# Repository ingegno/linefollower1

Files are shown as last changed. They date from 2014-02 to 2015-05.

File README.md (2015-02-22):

linefollower1
=============

_Arduino code voor een lijn volg robot met object detectie, zoals geleerd bij Ingegno Team 2013-2014 workshop, zie [ingegno.be](http://ingegno.be)._

Arduino code for a line following robot, with object detection, as teached at Ingegno Team 2013-2014 workshop, see [ingegno.be](http://ingegno.be).

## Lasercut frame

_Gebruik het frame in  [frame_redder.svg] (../master/frame/frame_redder.svg) als basis voor je robot. Geen toegang tot een lasercutter? Gebruik dan een plank van 7x12 cm, 3mm dik, als basis._

Use the frame from [frame_redder.svg] (../master/frame/frame_redder.svg)  as basis for your robot. No lasercutter? Use a piece of 7x12cm as basis, 3mm thick. 

## BOM

- Arduino Uno
- Afstandssensor 
- 2 x Lijnsensor
- 2 Servo motoren
- 2x 2AA Batterijpak
- Veel draadjes
-  Mini schakelbord (breadboard)
- Een schakelaar
- Zwenkwiel
- Bouten en moeren
- 4x AA batterijen
- Wielen (bv Nutella doppen)
- een frame (plank 7x12 cm of ons lasercut frame

## Lessons

_Doe de sketches in [de sketches folder] (../master/sketches) een voor een onder begeleiding._

Do the sketches in [the sketches folder] (../master/sketches) one by one under supervision.

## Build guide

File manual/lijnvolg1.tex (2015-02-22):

\section{\engt{Appendix} \nedt{Appendix}}
\eng{TODO
}

\ned{Lijnvolg sketches
}

\subsection{\engt{Test Servo} \nedt{Test Servo's}}
\eng{todo}
\ned{Volgende code bevat hoe je de Servo motoren kunt controleren. De eerste sketch toont hoe je precies een Servo definieert in Arduino code, en hoe je opdrachten ernaar stuurt.}

\begin{code}[les01\_servo.ino]\label{c:a1_servo}
 \ \newline
\inputardfull{\string"../sketches/les01_servo/les01_servo.ino\string"}
\end{code}

\eng{todo}
\ned{Doe wat testen met bovenstaande code. Het is voor het verdere verloop belangrijk dat je functionaliteit van je robot opsplitst in deeltjes die apart niet moeilijk zijn om te verstaan. Zo hou je overzicht over het geheel. Onze volgende code herschrijft het aansturen van de servo motoren in zo'n codeblokjes, welke we functies noemen: je krijgt input, je doet daar iets mee, en dan eindig je.}

\begin{code}[les02\_servo\_functies]\label{c:a2_servof}
 \ \newline
\inputardfull{\string"../sketches/les02_servo_functies/les02_servo_functies.ino\string"}
\end{code}

\subsection{\engt{Test Distance Sensor} \nedt{Test Afstandssensor}}
\eng{todo}
\ned{Volgende code bevat een eenvoudige en een iets vluggere, maar moeilijkere, methode om de afstand tot een object te bepalen. Met een basiskennis Arduino kun je de code lezen. De workshop begeleider om raad vragen bij problemen!}

\begin{code}[les03\_afstandsensor.ino]\label{c:a3_distsens}
 \ \newline
\inputardfull{\string"../sketches/les03_afstandsensor/les03_afstandsensor.ino\string"}
\end{code}

\eng{todo}
\ned{De afstandssensor heb je getest, en je begrijpt hoe hij werkt. We hebben een bibliotheek geschreven om gemakkelijk met afstandssensoren te werken: DistSens.h. Maak een nieuwe sketch die die de bibliotheek gebruikt om de afstand te bekomen. Je dient het bestand DistSens.h in dezelfde folder op te slaan als je sketch (.ino bestand). 

De bibliotheek heeft volgende handleiding: 

Een afstandssensor wordt geactiveerd door een instantie van de \ardo{DistSens} klasse te maken, en de trigger en echo pin door te geven via de \ardo{attach()} methode. Je kan daarna de afstand op verschillende manieren opvragen. 
}
\nedt{
De methodes van een DistSens object zijn: 
\begin{itemize}
 \item \ardo{attach(pintrig, pinecho)} -  Welke pinnen gebruiken
 \item \ardo{stop()} - deactiveer, alle afstanden zullen 0 teruggeven
 \item \ardo{start()} - activeer terug na deactivering
 \item \ardo{setMinMax(min, max)} - Geef minimum en maximum afstand om te meten. Default: 3.5cm en 50cm
 \item \ardo{setResolution(res)} - Zet laagste interval waarna opnieuw meten afstand toegelaten is. Default = 250000UL = 250 millisec = 1/4 sec. \newline
 Een meting voor dit interval afgelopen is zal de vorige gemeten afstand teruggeven.
 \item \ardo{distSimple()} - afstandsmeting die je sketch blokkeert tot meting gedaan is, wat een ongekende hoeveelheid tijd is.
 \item \ardo{distTimeout()} - afstandsmeting die je sketch blokkeert voor maximaal te tijd nodig om de max afstand doorgegeven met \ardo{setMinMax} te metn + 1ms. Deze tijd is 
 2*max/(speed of sound) + 1
 \item \ardo{distNoblock()} - afstandsmeting die altijd een waarde teruggeeft in minder dan 1 milliseconde. De laatst gedane meting wordt teruggegeven zolang geen nieuwe meting be\"eindigt is. Deze method geeft enkele correcte resultaten als het opgeroepen wordt vanuit een \ardo{loop()} functie van je Arduino die niet van \ardo{delay()} gebruik maakt. Gebruik deze methode als je verschillende sensoren hebt om op te reageren en je niet wil dat de afstandssensor de reactie blokkeert (PS: wil je nog beter, gebruik dan interrupts, dit zit niet in deze bibliotheek).
\end{itemize}

Een voorbeeld van gebruik van deze bibliotheek is je autorobot met servo's en een afstandsensor een hindernissen parcours laten afwerken: rij door een kamer zonder ergens tegen te botsen!
}

\begin{code}[les04\_ontwijkobjecten.ino]\label{c:a4_distsens}
 \ \newline
\inputardfull{\string"../sketches/les04_ontwijkobjecten/les04_ontwijkobjecten.ino\string"}
\end{code}

\subsection{\engt{Test Line Sensor} \nedt{Test Lijnsensor}}
\eng{todo}
\ned{Test nu de lijnsensoren. Je moet ze zo plaatsen dat ze het verschil zien tussen een zwarte lijn en de rest. Volgende code gebruikt de seri\"ele monitor om te laten weten wat we uitlezen.}

\begin{code}[les06\_lijnsensor.ino]\label{c:a6}
 \ \newline
\inputardfull{\string"../sketches/les06_lijnsensor/les06_lijnsensor.ino\string"}
\end{code}

\subsection{\engt{Line Follower} \nedt{Lijnvolg robot}}
\eng{todo}
\ned{We hebben alles voor een lijnvolg robot. Alle stukjes samenvoegen en dan een strategie om hoe je reageert op de meting van de lijnsensor. Een goede strategie is niet te vlug te rijden, en dan bij het zien van de lijn links of rechts te draaien rond de as. }

\begin{code}[les07\_lijnvolgen.ino]\label{c:a7}
 \ \newline
\inputardfull{\string"../sketches/les07_lijnvolgen/les07_lijnvolgen.ino\string"}
\end{code}
%\begin{code}\label{c:l2_motor}
% \ \newline
%\inputard{\string"../sketches/calib_motors_rotate_axis/calib_motors_rotate_axis.ino\string"}{37}{54}
%\end{code}

%  we need a multiple of 4 as number of page!
\newpage

\begin{center}
\textcopyright 2015 Ingegno.be                                         \end{center}

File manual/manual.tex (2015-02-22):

\documentclass[8pt,a5paper]{article}
%\usepackage{a4wide}

\usepackage[english,dutch]{babel}
% better color management than parallel:
\usepackage{pdfcolparallel}

\setlength{\columnsep}{0.5cm}

%\usepackage{parallel}
\usepackage{color}
\usepackage{amsmath}
\usepackage{graphicx}

\usepackage{inconsolata} %a different monofont, texlive-fonts-extra needed!

\usepackage{arduinohighlight}

\usepackage{xcolor}
\usepackage{framed}
\colorlet{shadecolor}{gray!50}

\usepackage[
      %dvipdfm,    %put here the correct(!) driver you are using
      pdftex,
      unicode,
      colorlinks=true,    %no frame around URL
      urlcolor=blue,    %blue color
      menucolor=black,    %no colors
      linkcolor=blue,    %blue color
      bookmarks=true,    %tree-like TOC
      bookmarksopen=true,    %expanded when starting
      hyperfootnotes=false,    %no referencing of footnotes, does not compile
      pdfpagemode=UseOutlines,    %show the bookmarks when starting the pdf viewer
      pdfauthor={Ingegno.be},
      pdftitle={Line Follower - Ingegno.be},
]{hyperref}

\newtheorem{opdrE}{Task} 
\newenvironment{doE}
  {\begin{shaded}\begin{opdrE}}
  {\end{opdrE}\end{shaded}}

\newtheorem{opdrN}{Opdracht} 
\newenvironment{doN}
  {\begin{shaded}\begin{opdrN}}
  {\end{opdrN}\end{shaded}}
\newtheorem{code}{Code} 

%% First to \eng, then \ned, closes automatically with a paragraph
% \newcommand{\eng}[1]{\selectlanguage{english} \ParallelLText{#1}}
% \newcommand{\ned}[1]{\selectlanguage{dutch} \ParallelRText{#1} \ParallelPar}
% \newcommand{\engt}[1]{{#1} - }
% \newcommand{\nedt}[1]{{#1}}
% \newcommand{\engo}[1]{\eng {#1}}
% \newcommand{\nedo}[1]{\ned {#1}}

%% Use following for book in English language
% \usepackage{multicol}
% %\newcommand{\eng}[1]{\selectlanguage{english} {#1}}
% \newcommand{\eng}[1]{\begin{multicols}{2}{\selectlanguage{english} {#1}}\end{multicols} \hrule}
% \newcommand{\ned}[1]{ }
% \newcommand{\engt}[1]{{#1}}
% \newcommand{\nedt}[1]{ }
% \newcommand{\nedo}[1]{ }
% \newcommand{\engo}[1]{\selectlanguage{english} {#1}}

%% Use following for book in Dutch language
\usepackage{multicol}
%\newcommand{\ned}[1]{\selectlanguage{dutch} {#1}}
\newcommand{\ned}[1]{\begin{multicols}{2}{\selectlanguage{dutch} {#1}}\end{multicols} \hrule}
\newcommand{\eng}[1]{ }
\newcommand{\nedt}[1]{{#1}}
\newcommand{\engt}[1]{ }
\newcommand{\engo}[1]{ }
\newcommand{\nedo}[1]{\selectlanguage{dutch} {#1}}

%\selectlanguage{english}
% \ParallelLText{\blindtext}
%\selectlanguage{dutch}
%\ParallelRText{\blindtext}
%\ParallelPar

	\addtolength{\oddsidemargin}{-.5in}
	\addtolength{\evensidemargin}{-.5in}
	\addtolength{\textwidth}{1.in}

	\addtolength{\topmargin}{-.5in}
	\addtolength{\textheight}{1.25in}

\begin{document}

 \title{Lijnvolger robot!}
 \author{Ingegno Team: M.C. Ciocci, B. Malengier}
 \date{\today}
 \maketitle

\begin{figure}[h]
  \centering
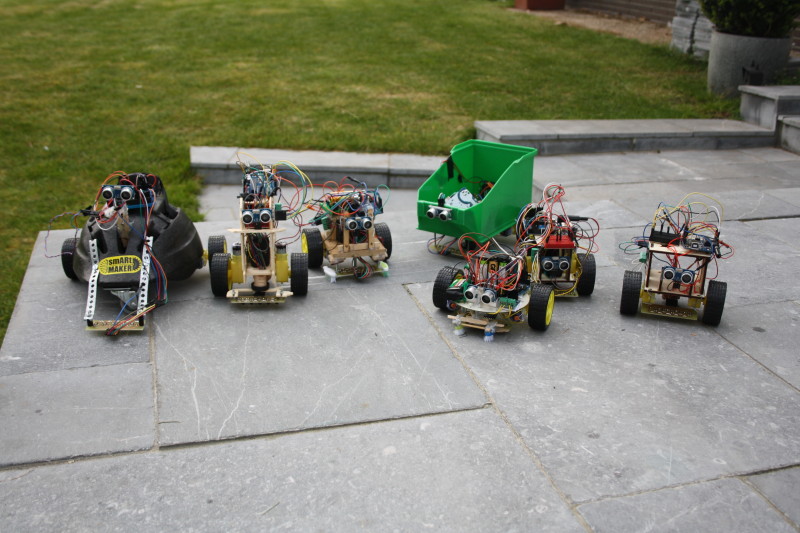
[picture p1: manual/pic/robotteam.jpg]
  
  
%\caption{\engt{Ingegno line following robots}
%\nedt{Ingegno lijnvolg robots}}
\label{f:ingrobots}       % Give a unique label
\end{figure}

\begin{Parallel}{7.5cm}{7.5cm}

\input{lijnvolg1}

\end{Parallel}
\end{document}

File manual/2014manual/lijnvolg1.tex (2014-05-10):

\section{\engt{Introduction} \nedt{Introductie}}
\eng{TODO
}

\ned{We maken een lijnvolg robot. Dit is een ingewikkeld project, met veel programmatie. Je kan het op twee manieren aanpakken: de bijgeleverde programma's als gegeven beschouwen en je concentreren op het optimaal maken van de robot. Je kan met de uitleg van deze handleiding de delen van de programma's die meest invloed hebben op het gedrag aanpassen. Kun je al wat meer, probeer dan ook de programma's door te nemen.
}

\subsection{\engt{The components} \nedt{De componenten}}
\eng{We will need the following components: 
\begin{enumerate}
 \item Arduino Uno
 \item Motor Shield 2.5V to max 12V
 \item Echo distance sensor 
 \item line scan sensor
 \item 2 motors (sufficiently powerfull!)
 \item Arduino connector for power to 9V
 \item many wires
 \item mini breadboard
 \item two switches to interrupt the power easily
\end{enumerate}
You will also need a soldering iron, and construction material for the robot. We offer some lasercut designs, but you can use whatever design you like as long as all components fit on it.

For an overview of meaning of the components, see the cheat sheet distributed seperately.
}

\ned{We zullen volgende componenten gebruiken: 
\begin{enumerate}
 \item Arduino Uno
 \item Motor Shield 2.5V tot max 12V
 \item Echo afstandssensor 
 \item line scan sensor
 \item 2 motoren (voldoende krachtig!)
 \item Arduino connector voor stroom naar 9V
 \item veel draden
 \item mini schakelbord
 \item twee schakelaars om de stroom snel te kunnen uitschakelen
\end{enumerate}
Je zal ook een soldeerijzer nodig hebben, en constructiemateriaal voor je robot. We geven een aantal lasercut ontwerpen, maar je kan gelijk welk design gebruiken die je wil, zolang alle componenten er maar op passen.

Voor een overzicht van de betekenis van de componenten, zie het overzicht die je apart gekregen hebt.
}

\subsection{Arduino}
\eng{We will make intensive use of Arduino, so you need to install the \href{http://Arduino.cc}{Arduino software}. Once installed, you can connect the Arduino to your PC via de \textsc{usb} port.  In the programming environment you installed you can write programs, and load those on the Arduino board. They will be executed there as long as the Arduino has power.

}
\ned{We zullen intensief gebruik maken van Arduino, dus moet je de \href{http://Arduino.cc}{Arduino software} installeren op je laptop.
Eenmaal geinstalleerd kun je nu je Arduino koppelen aan je computer via de \textsc{usb} poort. In de programmeeromgeving van Arduino kun je programma's schrijven en die opladen naar de Arduino, waar ze dan uitgevoerd worden zolang er stroom is.
}

\subsection{\engt{Programming with Arduino} \nedt{Programmeren met Arduino}}
\eng{A programming language needs to be understood by a computer. Unfortunately computers are still a little bit dumb, so you are not allowed to make errors! It's like a writing contest in which you need to obtain a 10/10 every time. So take time to learn the form of the language. See the specific sheet 'Programming with Arduino' distributed with this manual.}

\ned{Een programmeertaal moet verstaan worden door een computer. Spijtig genoeg zijn computers nog altijd een beetje dom, dus mag je geen enkele fout maken! Het is zoals een dictee waar je altijd 10/10 moet halen. Neem dus de tijd om de structuur en taal van de Arduino te leren. Zie de blaadjes 'Programmeren met Arduino' die je bij deze gids kan downloaden.}

\section{\engt{Lesson 1: Start! Construction time} \nedt{Les 1: Start! Constuctie}}

\subsection{\engt{Wiring} \nedt{Bedrading}}
\eng{TODO}
\ned{In Figuur \ref{f:wiring} zie je hoe al de componenten aan elkaar moeten verbonden worden. Al deze zaken moeten op je robot passen. De bedrading die je ziet kun je vooraf maken, en dan bepalen hoe je een frame zult maken, en hoe je alles op elkaar zult passen. Het uittesten van alle componenten doen we dan later (al dan niet als het al op een frame zit). 

Voor de AA batterijen die voor Vin zorgen kun je ook krachtige Li-ion batterijen gebruiken. Zorg wel dat je niet meer dan 12V gebruikt. De AA batterijen kunnen veel stroom leveren, wat nodig is voor de motoren. De 9V batterij gebruiken we om de Arduino aan te sturen. Deze 9V batterij kan niet veel stroom leveren, maar de sensoren en de Arduino chip hebben niet veel stroom nodig, dus dat is ok.

Het motor shield die je hebt ziet er niet uit zoals op de figuur. Het concept is hetzelfde evenwel, je hebt 4 schroefconnectors voor de batterijen, 2 voor links, 2 voor rechts. Dan heb je 2 linkse pinnen: PWM en DIR, 2 rechtse pinnen: PWM en DIR. Deze zijn voor de controle van de motoren: hoe snel moeten ze gaan. En dan nog Vin en GND pinnen voor de stroom.

De echo-locator herken je aan de twee ogen. Zet ze niet te hoog zodat je obstakels kunt zien. Er zijn 4 pinnen aan deze sensor: Trig en Echo om de afstand tot een object te bepalen, en dan de VCC en GND voor de stroom, welke 5V \textbf{moet} zijn. 

De lijn scanner heeft 7 pinnen. Voor de stroom opnieuw een VCC en GND, welke opnieuw 5V \textbf{moet} leveren, en dan nog 5 pinnen voor de 5 sensoren die je onderaan ziet. Opgelet, deze sensoren moeten ongeveer 3mm boven de grond hangen. Maak dus een constructie die je toelaat dit wat aan te passen zodat je de juiste hoogte kan instellen.

We gebruiken een mini-schakelbord om correct stroom te leveren. Gebruik een kant voor GND en 5V, en een andere kant voor GND en Vin van de AA batterijen. Schrijf het met alcohol stift op de zijkant, zodat je zeker niet mist. Teveel stroom op de sensoren of de Arduino \textbf{zal} deze kapot maken!
}

\begin{figure}
  \centering
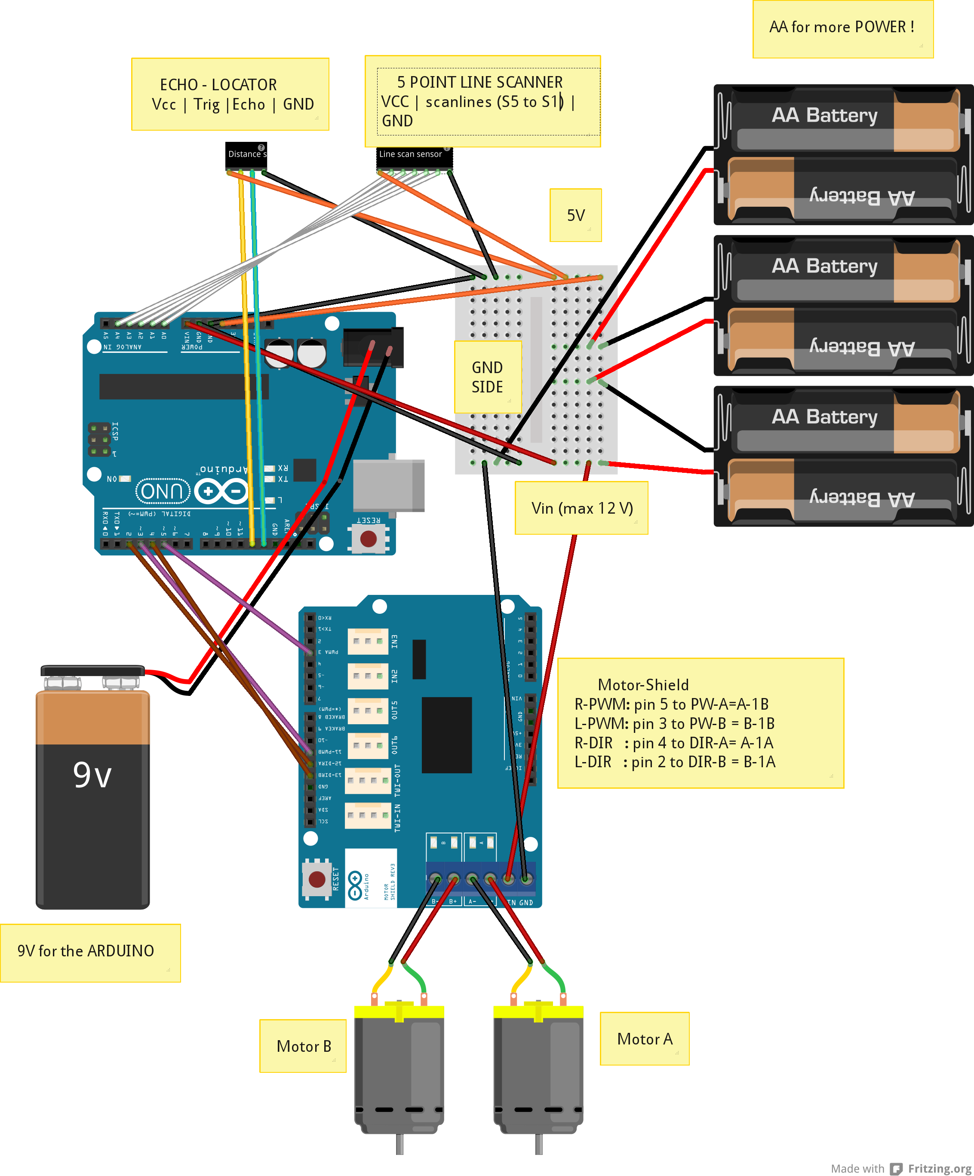
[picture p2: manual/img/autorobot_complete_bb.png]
  
\caption{\engt{The full wiring, all of this must fit on your robot}
\nedt{De volledige bedrading, dit moet helemaal op je robot passen}}
\label{f:wiring}       % Give a unique label
\end{figure}

\subsection{\engt{Construction} \nedt{Constructie}}

\begin{figure}[h]
  \centering
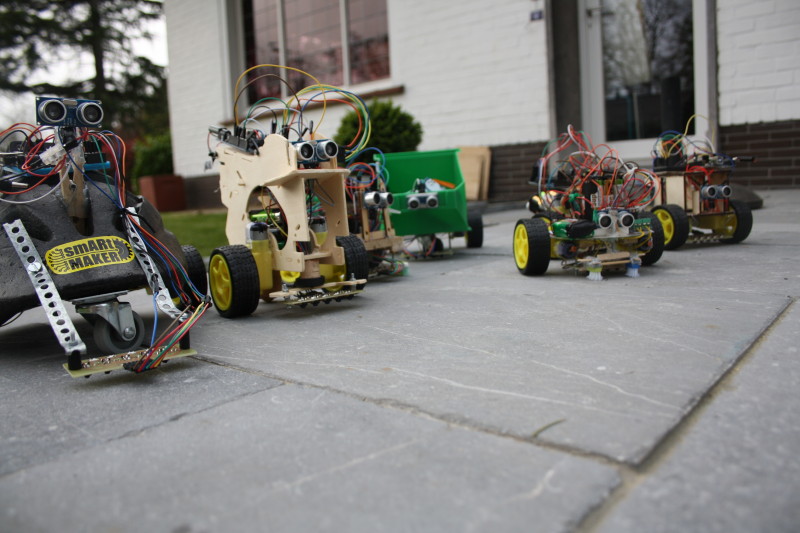
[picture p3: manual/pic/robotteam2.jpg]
  
\caption{\engt{Ingegno line following robots}
\nedt{Ingegno lijnvolg robots}}
\label{f:ingrobots2}
\end{figure}

\eng{TODO}
\ned{Je weet wat er op je robot moet komen, en kunt dus nu een eigen constructie maken uit materiaal die je hebt liggen. Voorbeelden zie je in Figuur \ref{f:ingrobots2}. 

Wil je optimaal werken, dan kun je een frame laten laseren in een fablab in de buurt. Je kan ontwerpfiles vinden in de map \url{https://github.com/ingegno/linefollower1/blob/master/frames/}. Wij zullen frame \textbf{basic} gebruiken. Alle stukken van basic zie je in Figuur \ref{f:frame_basic}, alsook de finale vorm. Voor de stevigheid gebruik je best ook lijm. Dit kan met houtlijm , of, veel gemakkelijker, met een lijmpistool.
}

\begin{figure}[h]
  \centering
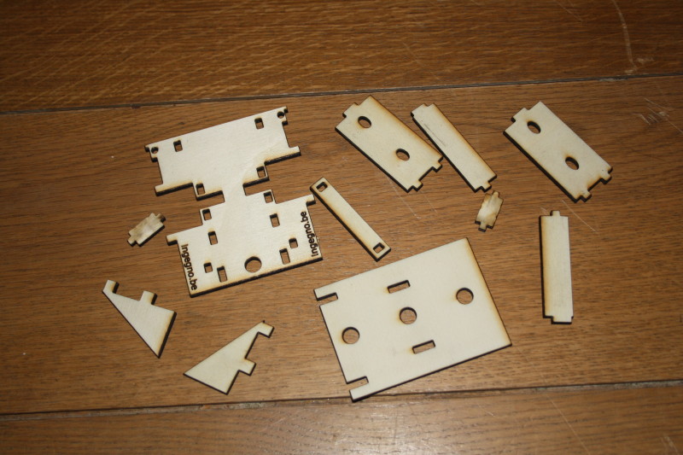
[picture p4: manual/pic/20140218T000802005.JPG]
  
%\rotatebox{-90}{\includegraphics[width=6cm]{pic/20140218T003500016.JPG}} \\
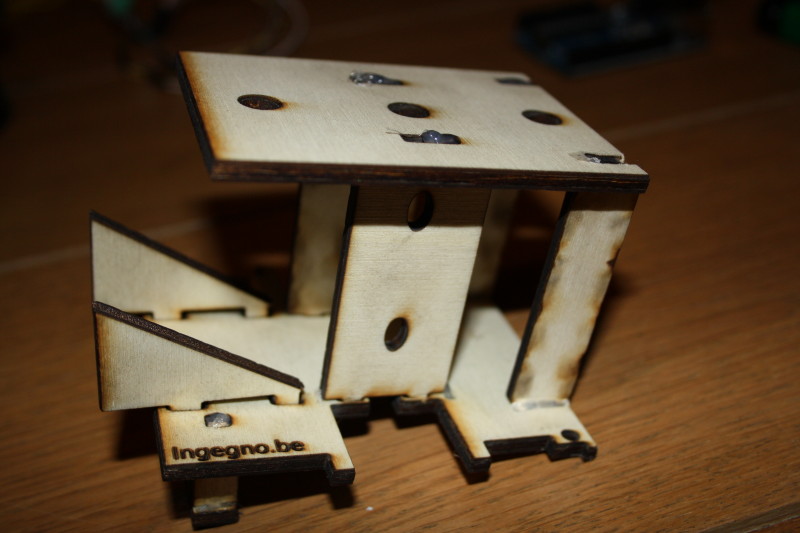
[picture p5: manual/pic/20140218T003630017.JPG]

\caption{\engt{Our basic frame, lasercut pieces, glued together form}
\nedt{Ons ``basic'' frame, de gelaserde stukken, en de samengelijmde vorm}}
\label{f:frame_basic}       % Give a unique label
\end{figure}

\eng{TODO}
\ned{Leg nu al je componenten klaar zoals in Figuur \ref{f:components}. We hebben hierbij de motoren reeds bedraad, en aan het motor shield bevestigd (motor A naar A en  motor B naar B). Verder hebben we met twee 3AA batterijhouders, een enkele houder van 9V gemaakt, en er een schakelaar aangehangen. Deze zal de motoren stroom leveren. Voor de Arduino gebruiken we een gewone 9V batterij waar we ook een schakelaar aangehangen hebbben, en een Arduino stroomplug die de Arduino van stroom zal voorzien. Ja, met al deze stukken kunnen we een robot maken, meer is niet nodig! Het wordt wel wat puzzelen om ze allemaal op ons basic frame te krijgen.
}

\begin{figure}[h]
  \centering
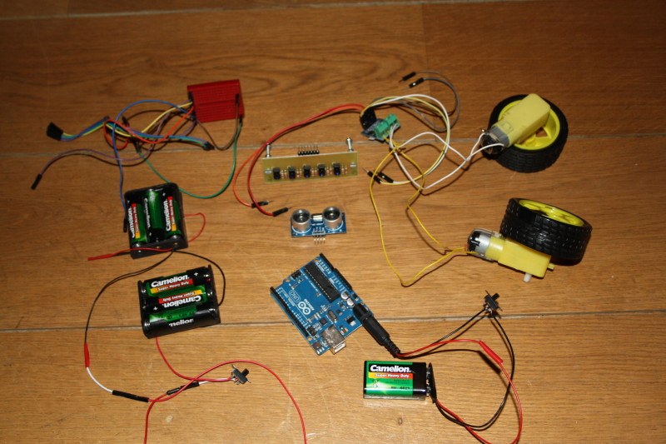
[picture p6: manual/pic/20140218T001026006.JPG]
  
\caption{\engt{All the components}
\nedt{Alle componenten}}
\label{f:components}       % Give a unique label
\end{figure}

\eng{TODO}
\ned{Stap 1 is het vastmaken van de motoren. Het basic frame is zo opgesteld dat deze rechtop staan. Lijm of bindt ze vast aan de rechtopstaande stukken van het frame, zie Figuur \ref{f:fr_motor}. Zorg dat beide motoren op gelijke hoogte staan en nergens tegen slepen. 

Stap 2 is het vastmaken van de lijnscanner. Let goed op wat er op de lijnscanner staat: met de pinnen aan de achterkant staat rechts VCC, en links GND. Daartussen zijn de scanlijnen, welke wij als 0 tot 4 zullen nummeren van rechts tot links, zie Figuur \ref{f:fr_scanlines}. The draden die je gebruikt moeten allen andere kleuren hebben zodat je later goed weet wat wat is. Je laat de draden via een gat onderaan naar boven lopen waar de Arduino zal komen. Met schroeven bevestig je de lijnscanner dan op een hoogte van 3 mm boven de grond als het frame horizontaal staat, zie Figuur \ref{f:fr_scanlines2}.
}

\begin{figure}[h]
  \centering
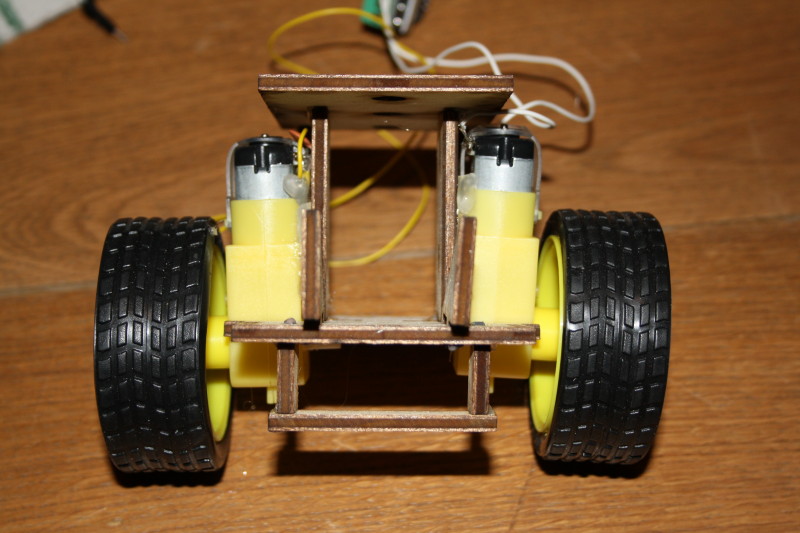
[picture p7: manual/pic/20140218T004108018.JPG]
  
\caption{\engt{The two motors glued to the frame}
\nedt{De twee motoren vastgelijmd op het frame}}
\label{f:fr_motor}       % Give a unique label
\end{figure}

\begin{figure}[h]
  \centering
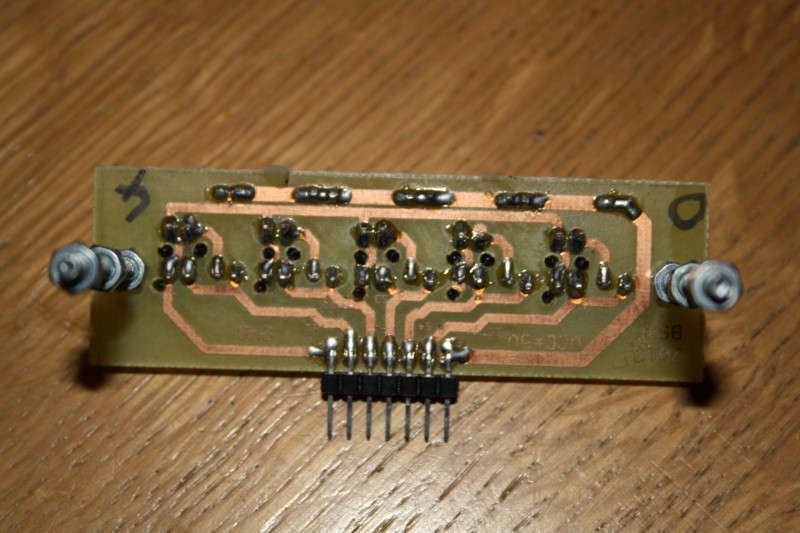
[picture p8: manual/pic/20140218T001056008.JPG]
  
\caption{\engt{The line scanner with 5 scan sensors}
\nedt{De lijnscanner met 5 scan sensoren}}
\label{f:fr_scanlines}       % Give a unique label
\end{figure}

\begin{figure}[h]
  \centering
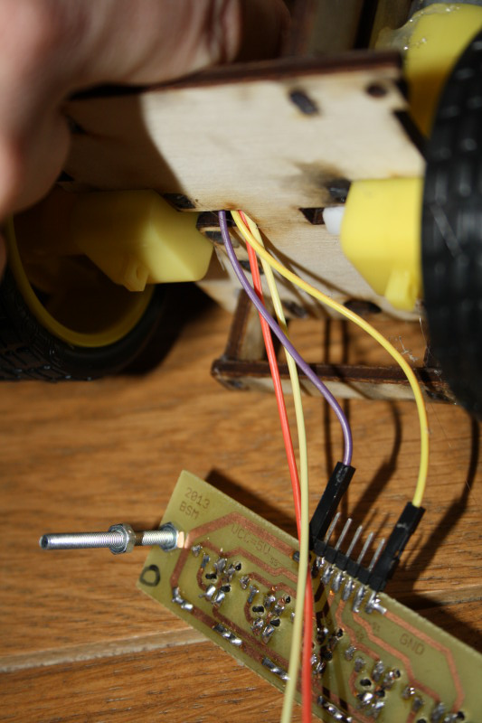
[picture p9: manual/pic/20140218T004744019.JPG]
  
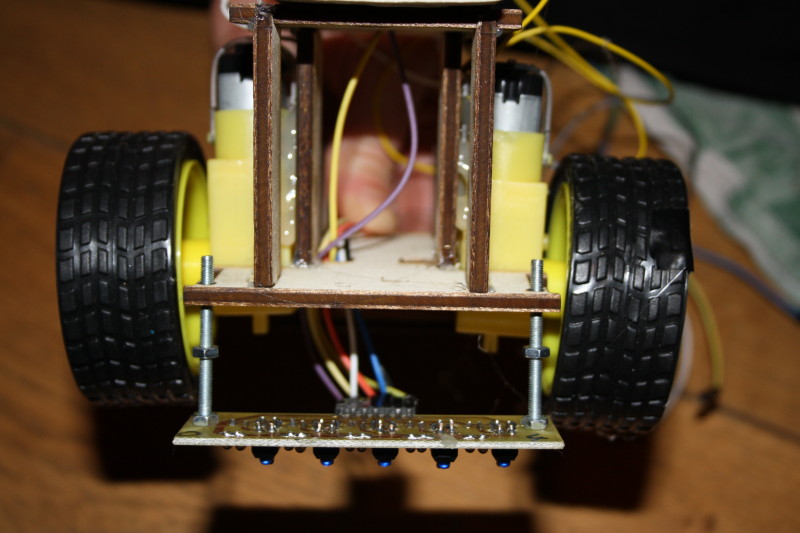
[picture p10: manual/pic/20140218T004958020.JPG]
  
\caption{\engt{Fixing the line scanner to the frame}
\nedt{De lijnscanner vastmaken aan het frame}}
\label{f:fr_scanlines2}       % Give a unique label
\end{figure}

\begin{figure}[h]
  \centering
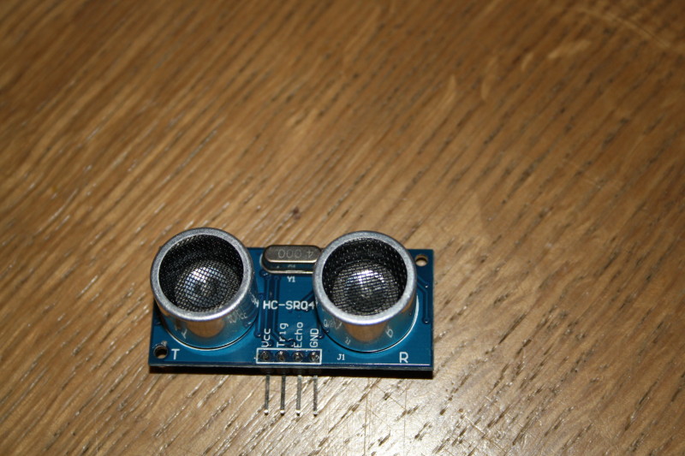
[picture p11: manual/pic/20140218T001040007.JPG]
  
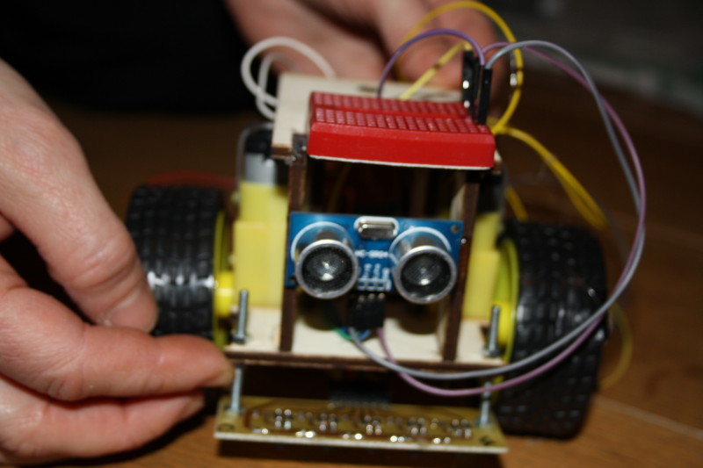
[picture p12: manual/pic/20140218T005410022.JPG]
  
\caption{\engt{The distance scanner are our eyes, and go to the front}
\nedt{De afstandssensor zijn onze ogen, en komen vooraan}}
\label{f:fr_dist}       % Give a unique label
\end{figure}

\eng{TODO}
\ned{Stap 3 is de afstandssensor, die vooraan komt en die vastmaakt op een hoogte waarmee we een blik kunnen zien. De sensor zou precies tussen de voorste pilaren moeten passen, je kan hem eraan binden of vastlijmen. De draden dienen naar boven te lopen, waar we \textbf{VOORAAN} ons mini-schakelbord lijmen. Op het schakelbord gebruiken we een lijn voor Vin, een lijn voor GND van Vin, een lijn voor 5V van de Arduino, en een lijn voor de GND van deze 5V. We gebruiken hiervoor de 4 uiterste lijnen, en schrijven het op het schakelbord in alcoholstift met +, -, Vin en -, zodat we later niet missen. Bevestig de GND en Vcc van de lijnsensor en de afstandssensor tot de - en de + (5V) op het schakelbord. Zie Figuur \ref{f:fr_dist}. Het schakelbord moet boven op het platform vooraan staan omdat we niet willen dat de lijnrobot naar voor kan hellen. De lijnsensoren moeten immers op 3mm boven de grond blijven, dus willen we het zwaarste gewicht (de batterijen) achteraan!

Stap 4 is het plaatsen van onze stroombronnen. Plaats de 9V batterij voor de Arduino tussen de pilaren, en de stroombron Vin voor de motoren (op de foto's de AA batterijen) erachter op de schuine delen. Dit zal ons hoofdgewicht vormen. We willen dat de robot voornamelijk naar achter leunt, maar zorg toch dat dat niet teveel is, zodat de robot niet teveel weegt op het achterste vast punt. De draden van de Vin gaan naar de Vin lijn en de GND lijn op ons schakelbord, zie Figuur \ref{f:fr_power}.
}

\begin{figure}[h]
  \centering
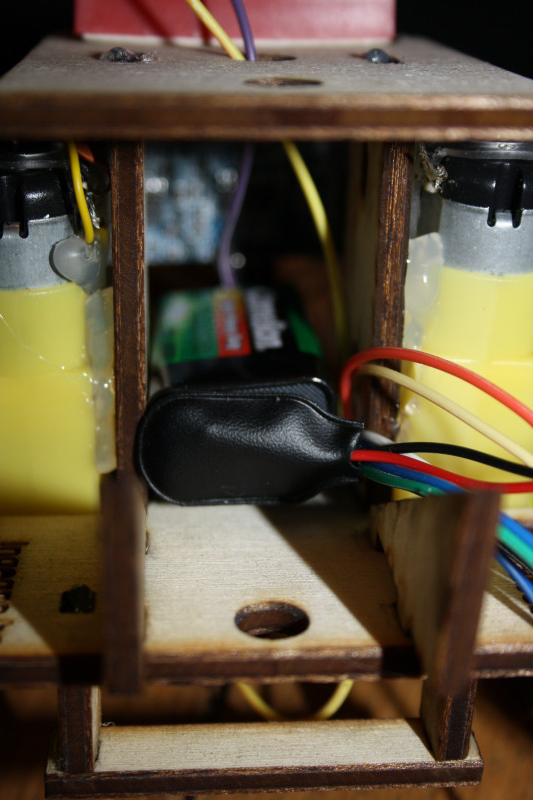
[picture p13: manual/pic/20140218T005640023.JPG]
  
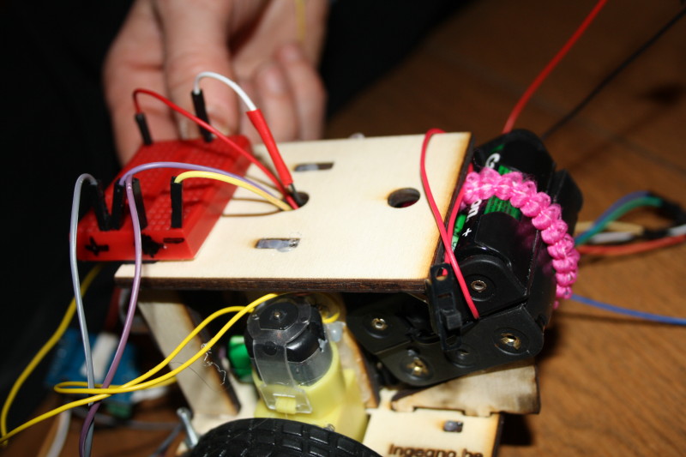
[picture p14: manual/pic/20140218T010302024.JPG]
  
\caption{\engt{The batteries go in the middle and the back}
\nedt{De batterijen gaan tussen de pilaren en langs achter op de spoiler}}
\label{f:fr_power}       % Give a unique label
\end{figure}

\eng{TODO}
\ned{Stap 5 is het plaatsen van de Arduino bovenaan op het frame. Connecteer de rest van de draden voor de lijnsensor en de afstandssensor: de lijnscan outputs gaan naar analoog 0 tot en met 4. Gebruik 0 voor de rechterkant, en 4 voor de linkerkant. Voor de afstandssensor gaat Trig naar pin 12, en echo naar pin 13, zie Figuur \ref{f:wiring} en foto's in Figuur \ref{f:fr_ard}.

Connecteer ok de stroom van de Arduino naar je schakelbord: De eerste GND naar de GND van 5V, en de tweede GND naar de GND van Vin. De Vin pin van de Arduino naar de Vin lijn op het schakelbord, en de 5V pin van de Arduino naar de + (5V) lijn.
}

\begin{figure}[h]
  \centering
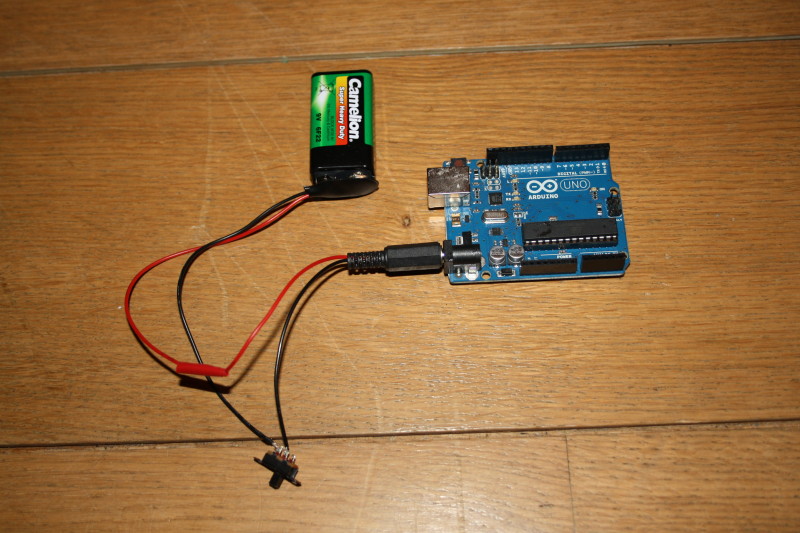
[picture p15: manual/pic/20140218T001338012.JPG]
  
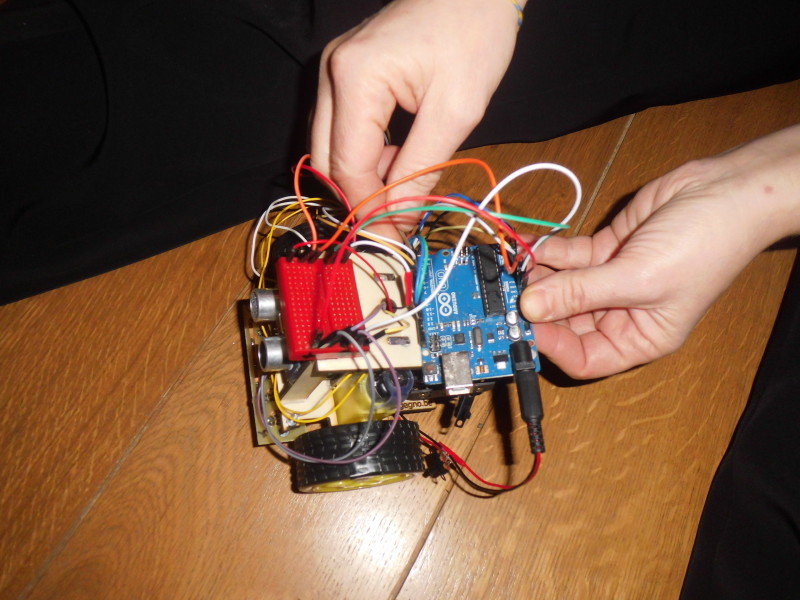
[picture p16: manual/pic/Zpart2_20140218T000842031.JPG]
  
\caption{\engt{Putting the Arduino on the frame}
\nedt{De Arduino komt bovenaan het frame}}
\label{f:fr_ard}       % Give a unique label
\end{figure}

\eng{TODO}
\ned{Stap 6 is het plaatsen van onze laatste component: het motor shield welke al bevestigd was aan de motoren. We stellen voor deze zijwaards op een pilaar te lijmen. De VCC en GND pin van het shield gaan naar de Vin en GND lijn van je schakelbord. Zie Figuur \ref{f:fr_shield}

Met de schakelaars kun je al eens testen: Met Vin zou motor shield LED moeten branden. Afhankelijk van je Arduino zal deze ook al werken en oplichten. Met enkel de Arduino 9V batterij zal enkel de Arduino LED oplichten.

Het motor shield heeft nog 4 extra pinnen: A-1A, A-1B, B-1A en B-1B. A- staat voor motor A, welke voor ons aan de linkerkant is. B- staat voor motor B welke aan de rechterkant is. De 1B pinnen zijn PWM (Pulse Width Modulation) pinnen en dienen dus te lopen naar PWM pinnen op je Arduino welke aangeduid zijn met een golfje: {$\sim$}. We stellen voor dat je doet zoals aangeduid in onze bedrading, Figuur \ref{f:wiring}, dus rechtermotor: B-1A naar pin 2 en B-1B naar pin 3, en voor linkermotor: A-1A naar pin 4 en A-1B naar pin 5.
}

\begin{figure}[h]
  \centering
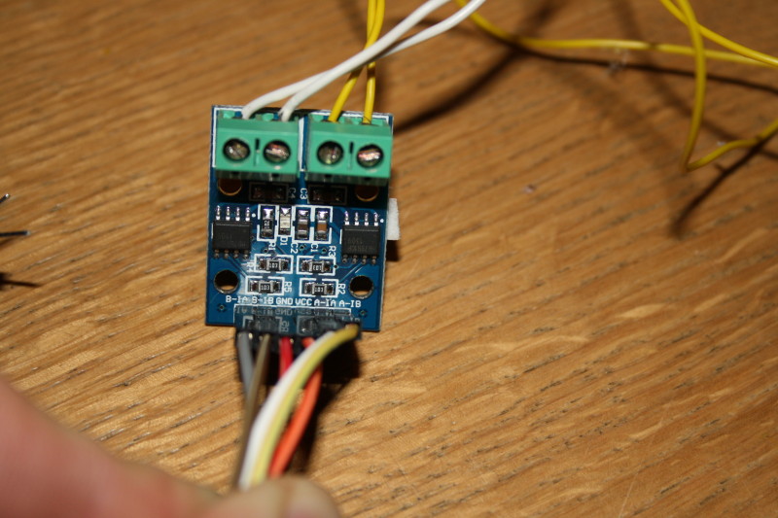
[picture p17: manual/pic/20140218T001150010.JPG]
  
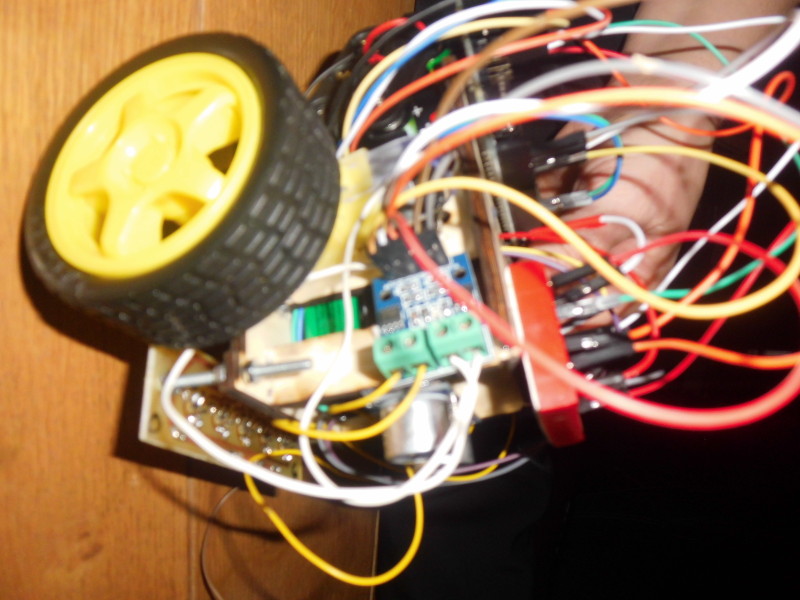
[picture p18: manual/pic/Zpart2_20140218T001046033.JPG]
  
\caption{\engt{The motor shield is attached to the side}
\nedt{Het motor shield komt aan de zijkant}}
\label{f:fr_shield}       % Give a unique label
\end{figure}

\eng{TODO}
\ned{Stap 7 is de balans van de robot. Onderaan aan de achterkant plaats je een wieltje of plak je een kraal zodat de platformen van de robot vlak zijn. Als je een kraal plakt zoals ons, zorg dan wel dat het oppervlak dat sleept op de grond minimaal is, en dat je een materiaal gebruikt dat goed glijdt. Je wil immers niet dat de motoren teveel kracht verliezen om de kraal vooruit te trekken, zeker niet als het meeste gewicht van de batterijen op de kraal leunt.

Als je een wieltje gebruikt dien je te zorgen dat deze zonder probleem kan draaien. Een wiel dat zijwaards sleept als we draaien (bv linkerwiel staat stil als rechter vooruit draait) zal immers meer problemen geven dan een kraal!
}

\eng{TODO}
\ned{Stap 8 is algemene schoonmaak: ziet het er goed uit? Gebruik lintjes om de kabels ordentelijk weg te moffelen. Gebruik wat versiering om je robot er geduchter te laten uitzien! Wat je ook doet, stuur ons een mailtje met je kunstwerk!
}

\newpage
\section{\engt{Lesson 2: Drive!} \nedt{Les 2: Rijden maar}}
\eng{TODO}
\ned{We beginnen met de motoren uittesten. Is links echt links? Is vooruit echt vooruit? Laad de code uit Code \ref{c:l1_motor} op je Arduino, en volg mee in de code of robot doet wat het programma opgeeft. 

Als het fout gaat dien je de connecties op je motor shield aan te passen. Links met rechts wisselen is A en B omwisselen. Vooruit in achteruit veranderen op A is de draden van A omwisselen. Idem voor B vooruit in achteruit wijzigen.

Hoe werkt het programma? Wel, we definieren eerst op welke pinnen onze motors zitten. De Dir pinnen geven de richting aan: vooruit of achteruit. Als je het goed deed zou \ardo{LOW} moeten vooruit zijn, en \ardo{HIGH} achteruit. De Dir pinnen zetten is evenwel niet genoeg. Je moet ook doorgeven via PWM pinnen hoeveel kracht de wielen moeten hebben, dus hoe snel ze moeten draaien. Voor \ardo{LOW} is dat een waarde van 0 tot 255, met 0 stilstaan en 255 de maximale snelheid. Voor \ardo{HIGH} is het omgekeerd: een waarde van 255 tot 0 met 255 stilstaan, en 0 de maximale snelheid.

Om eenvoudig te werken schrijven we een functie \ardo{void motor_drive (int right_speed, int left_speed)}. Deze functie krijgt als parameter de snelheid mee waarmee we willen dat de motor werkt. Dit dienen waarden tussen -255 en 255 te zijn. Negatieve getallen interpreteren we als achteruit, positieve als vooruit.

Het is belangrijk dat je de calibratiewaarden correct zet voor jou robot. Wat is de hoogste snelheid die je wil? Wat is de waarde van PWM die zorgt dat motor niet langer beweegt voor jou? Indien je robot niet op een rechte lijn rijdt bij vooruit, dien je ook links en rechts te corrigeren om dit juist te krijgen. Dit zijn \ardo{calib_speed_corrR} en \ardo{calib_speed_corrL} in de Code.
}

\begin{code}\label{c:l1_motor}
 \ \newline
\inputardfull{\string"../sketches/calib_motors_forward/calib_motors_forward.ino\string"}
\end{code}

\eng{TODO}
\ned{Als de vorige code goed werkte, gaan we over op de volgende test: rond de as draaien. De aangepaste \ardo{loop} functie staat in Code \ref{c:l2_motor}. Het enige dat verschillend is is dat we nu ook negatieve waarden gebruiken om roteren rond de as te verkrijgen. We draaien eerst anti-klokwijs, en dan volgens de klok. Telkens voor 3 seconden. 
}

\begin{code}\label{c:l2_motor}
 \ \newline
\inputard{\string"../sketches/calib_motors_rotate_axis/calib_motors_rotate_axis.ino\string"}{37}{54}
\end{code}

\engo{\begin{doE}
     With the two previous codes you have everything to write a predetermined circuit. So, decide on the circuit you want your robot to follow, and change the \ardo{loop} function of the previous code so that your robot performs the circuit you decided.
     \end{doE}
}
\nedo{\begin{doN}
     Met de twee vorige codes heb je alles om je eigen voorgeprogrammeerd parcours af te leggen. Beslis een parcours die je wil dat je robot aflegd, en wijzig de \ardo{loop} functie van je vorige code om dit parcours te verkrijgen. 
     \end{doN}
}

\section{\engt{Lesson 3: Light sensor setup} \nedt{Les 3: een lichtsensor gebruiken}}
\eng{TODO}.
\ned{De tweede stap is het monteren van de lichtsensor. De lichtsensor kan kleuren detecteren onder de sensor.}

\begin{code}\label{c:l2_c}
 \ \newline
\inputardfull{\string"../sketches/calib_light_sensor_setpoint_line_follow/calib_light_sensor_setpoint_line_follow.ino\string"}
\end{code}

\section{\engt{Lesson 4: Follow a line} \nedt{Les 4: Een lijn volgen}}
\eng{TODO}.
\ned{Met motoren en de lichtsensor kunnen we een lijn volgen
}

\subsection{\engt{Basic version: move to midline} \nedt{Basisversie: beweeg naar een middellijn}}

\eng{TODO}
\ned{Ons basisalgoritme werkt op basis van volgend principe: 
\begin{enumerate}
 \item We lezen de lichtsensor in. We bepalen het middelpunt zoals in les 2: gewogen gemiddelde van de 5 sensoren. Gezien deze van 0 tot en met 4 lopen, zou het midden 2 moeten zijn. 
 \item De fout is het verschil van het gemeten middelpunt en het gewenste middelpunt, maal 1000. We willen deze fout zo klein mogelijk houden.
 \item Op basis van de fout passen we de snelheid van de motoren aan in de functie \ardo{calc\_turn}. De snelheid van de motoren is een getal tussen \ardo{min\_speed} en \ardo{max\_speed}, waarbij de eerste de waarde van PWM is die overeenkomt met stilstand (typisch 0), en \ardo{max\_speed} de maximum snelheid die je wil (typisch 180 tot 254). We corrigeren de snelheid van de linker of rechtermotor dus met
$$\frac{\mathrm{fout}}{\mathrm{max\_fout}} \times ( \mathrm{max\_speed} - \mathrm{min\_speed} ).
$$
 \item De correctie wordt verminderd van de snelheid van het wiel dat rotatie in de correcte richting veroorzaakt.
\end{enumerate}
}

\begin{code}\label{c:l3_c}
 \ \newline
\inputardfull{\string"../sketches/calib_forward_line_follow/calib_forward_line_follow.ino\string"}
\end{code}

\subsection{\engt{Extended version: types of lines} \nedt{Uitgebreide versie: type lijnen}}

\eng{TODO}
\ned{Ons basisalgoritme werkt op eenvoudige, traag draaiende lijnen. Zodra het wat sneller gaat, of bij scherpe bochten gaat het mis. Er kunnen verschillende manieren bedacht worden om dit op te lossen. 

Laat ons de volgende aanpak kiezen: we bepalen een type lijn. In plaats van enkel in \ardo{sensors_read()} te bepalen of we een lijn zien of niet, onderscheiden we volgende gevallen, die we als geheel getal (integer, dus int) teruggeven:
\begin{enumerate}
 \item \ardo{#define LS\_UNKNOWN    0 // we kunnen niet bepalen wat we zien}
 \item \ardo{#define LS\_BLACKLINE  1 // een zwarte lijn}
 \item \ardo{#define LS\_BLACKFIELD 2 // een zwart veld}
 \item \ardo{#define LS\_WHITEFIELD 3 // een wit veld}
 \item \ardo{#define LS\_BLACKLEFT  4 // zwart afbuigend naar links}
 \item \ardo{#define LS\_BLACKRIGHT 5 // zwart afbuigend naar rechts}
 \item \ardo{#define LS\_BLACKSPLIT 6 // zwart links en rechts, niet midden}
\end{enumerate}
Pas de functie \ardo{sensors_read()} aan om op basis van de gemeten waarden te bepalen wat er gebeurt. Pas dan de \ardo{loop()} functie aan met een switch op basis van het resultaat: \ardo{switch (sensors_read())}. Voor \ardo{LS\_BLACKLINE} is het zoals in de basisversie, maar doe nu andere bewegingen in de andere gevallen.

Onze aanpak kun je vinden op \url{https://github.com/ingegno/linefollower1/blob/master/sketches/calib_forward_line_follow_extend/calib_forward_line_follow_extend.ino}.
}

\section{\engt{Lesson 5: Distance to an object} \nedt{Les 5: Afstand tot een object.}}
\eng{TODO}

\ned{We plaatsen nu ogen op onze robot. De ogen zijn in werkelijkheid ultrasone sensoren, die de afstand bepalen tot objecten voor zich op dezelfde wijze als vleermuizen dat doen. 

De code kan gevonden worden in \ref{c:l4_c}.
}

\begin{code}\label{c:l4_c}
 \ \newline
\inputardfull{\string"../sketches/calib_distance_sensor/calib_distance_sensor.ino\string"}
\end{code}

\section{\engt{Lesson 6: Search and push object} \nedt{Les 6: Zoek en duw object.}}
\eng{TODO}

\ned{Integreer nu de code uit les 4 in de code van les 3. Zorg dat de robot niet rijdt als niet op een zwarte lijn. We zullen nu het volgende probleem beschouwen: Veronderstel dat je op een zwarte lijn was, en op een wit veld komt. Verifieer of dat waar is (dus je echt op een zwarte lijn was). Zoek op het witte veld een object, en duw het uit het veld.

In de code zullwen we dus in het geval van \ardo{case LS\_WHITEFIELD:}, code uitvoeren om dit te bereiken. Gezien onze code in de loop de lijn probeert te lezen, en we nu iets anders moeten doen dat vastligt (zoeken, bewegen naar, en dan wegduwen), doen we alles zonder gebruik te maken van de Arduino loop. Met andere woorden, we gebruiken de \ardo{while (allesok)} constructie om acties te laten voortduren tot we een gewenst resultaat hebben.

De veranderingen kunnen gevonden worden in  \url{https://github.com/ingegno/linefollower1/blob/master/sketches/linefollow_search_push/linefollow_search_push.ino}. Specifiek is het nodig om zeker te zijn dat we op het witte veld zijn. We willen immers niet te vroeg beginnen met zoeken. Indien ok, voeren we drie functies uit: \ardo{search_object();}, \ardo{move_to_object();}, and \ardo{push_object();}. Deze functies doen precies wat ze zeggen: ronddraaien om blik te zoeken. Zodra gevonden, bewegen naar het object, en uiteindelijk het een eind duwen zodat het buiten het veld komt.
}

\section{\engt{Extra: Robot dog} \nedt{Extra: Robothond}}
\eng{TODO}
\ned{Voor de lijnvolg robot moet je altijd een lijn hebben om het te tonen aan de mensen. We hebben eerder al een voorgeprogrammeerd parcours als oefening gedaan, dus ook dat kun je als demonstratie gebruiken. Met onze robot kunnen we nog iets anders doen: een robothond maken die je overal volgt.

Het idee is als volgt: onze robot zoekt zoals in de laatste les naar het object in zijn buurt, en rijdt er dan naartoe. Als object beweegt zoekt hij opnieuw. We hergebruiken dus verschillende elementen die we reeds eerder tegenkwamen.

Belangrijkste aspect in dit programma is opgeven tot op welke afstand gekeken moet worden. We doen dit nu tot op 40cm. Doe dus testen in een open ruimte waar muren of stoelen verder zullen staan!

De code vind je op \url{https://github.com/ingegno/linefollower1/blob/master/sketches/calib_forward_line_follow_extend/calib_forward_line_follow_extend.ino}.

Veel succes!
}

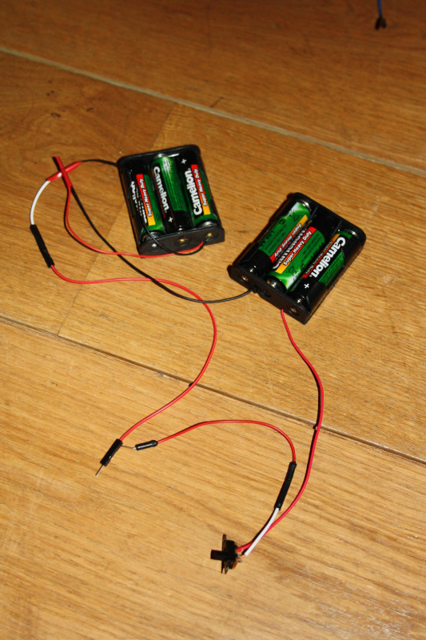
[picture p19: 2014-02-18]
manual/pic/20140218T001328011.JPG

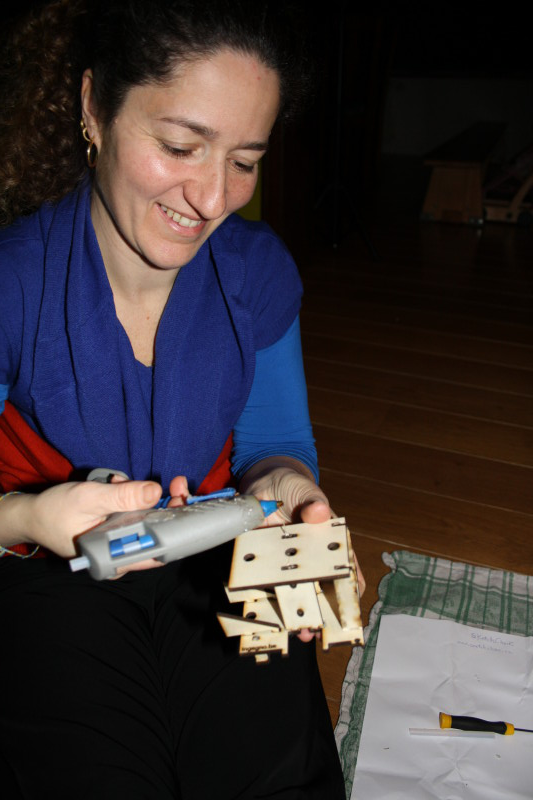
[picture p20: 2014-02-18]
manual/pic/20140218T003500016.JPG

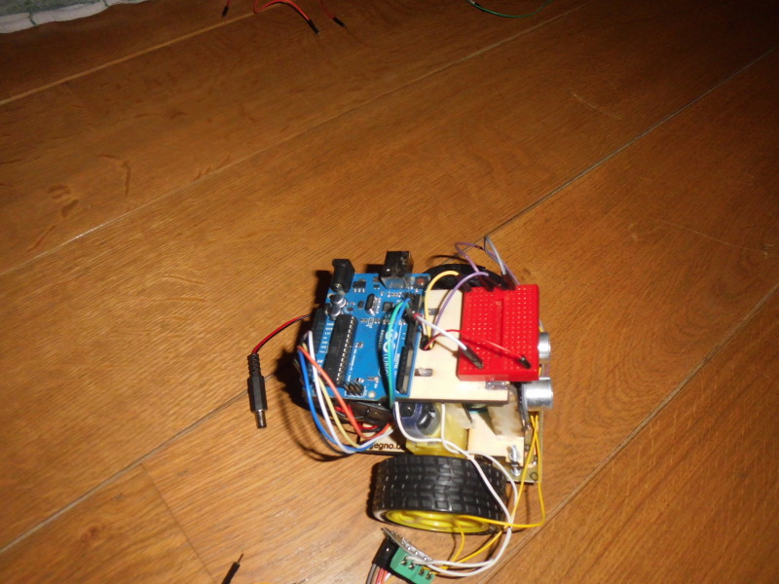
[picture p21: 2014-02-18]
manual/pic/Zpart2_20140218T000518029.JPG

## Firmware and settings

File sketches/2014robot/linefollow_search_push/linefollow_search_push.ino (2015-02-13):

/************************************************************/
/*          Look around: push object away on WHITEFIELD     */
/************************************************************/

// typ hier de aansluitingen van de motordriver, voor de twee motors
#define motorrechtsPWM 3
#define motorrechtsDir 2
#define motorlinksPWM  5
#define motorlinksDir  4

//callibration variables
int calib_speed_corrR = 0;  //if motors deviate, correct it
int calib_speed_corrL = 0;  //if motors deviate, correct it

//robots
#define SAYA    0
#define GUDRUN  1
#define THIEMEN 2
#define JASPER  3
#define BLSTEF  4
#define STEF    5
#define MLOUISE 6
int ROBOT = SAYA;

//new batteries
#define newbat false

int calib_max_speed, calib_no_speed, SLOW_SPEED, search_turn_speed;
//based on sensors an extra slowdown can be set, it will be substracted from the speed!
int extra_slowdown=0;
unsigned long slowdown_start = 0UL;

// afstandsmeting
#define trigPin 12
#define echoPin 13
//speed of sound in air in cm/micros
#define SPEED_SOUND 0.034
//the max distance in cm we want to measure
#define MAX_DIST 70.
//timeout to wait for echo pulse in microseconds
unsigned long timeout_echo = (2* MAX_DIST+1) / SPEED_SOUND;

bool test=false;

//geen PID control http://en.wikipedia.org/wiki/PID_controller
// enkel proportioneel de afwijking van middellijn in rekening brengen

#define SCHAAL_FOUT 1000

int black[2]  = {600,1100}; // hiertussen zouden de waarden voor zwart moeten zijn
int white[2]  = { 0, 500};
// correction callibration
int corrwhite[5] = {0,0,0,0,0};
int corrblack[5] = {0,0,0,0,0};

// Wat kunnen we zien met 5 sensoren van lijnsensor?
#define LS_UNKNOWN    0 // we kunnen niet bepalen wat we zien
#define LS_BLACKLINE  1 // een zwarte lijn
#define LS_BLACKFIELD 2 // een zwart veld
#define LS_WHITEFIELD 3 // een wit veld
#define LS_BLACKLEFT  4 // zwart afbuigend naar links
#define LS_BLACKRIGHT 5 // zwart afbuigend naar rechts
#define LS_BLACKSPLIT 6 // zwart links en rechts, niet midden
#define LS_BLACKEXTREMELEFT  7 // zwart uiterst links
#define LS_BLACKEXTREMERIGHT 8 // zwart uiterst rechts
#define LS_BLACKBANKLEFT     9 // zwart uiterst rechts
#define LS_BLACKBANKRIGHT   10 // zwart uiterst rechts

//wijzigende variabelen
float sensors_average;
float sensors_average_bl; // hier houden we rekening met een baseline, dat is we trekken het minimun ervan af

float mid_point = 2; //midden van de sensoren 0,1,2,3,4
float max_err = max(4-mid_point, mid_point-0) * SCHAAL_FOUT;
float min_err = 0.5 * SCHAAL_FOUT;
long error_value;

// Array om de 5 sensorlezingen in op te slaan
long sensors[5] = {0, 0, 0, 0, 0};

//enkele extra variabelen
// hoeveel verschil moet er zijn tussen grootste en kleinste waarden 
// om te zeggen dat er een lijn gezien is
#define ACCURACY 100

int speed_corr;
int right_speed;
int left_speed;
int turn_correction;
int backward_speed;
unsigned long backward_time;   //ms to drive backward
int corr_pushL, corr_pushR;


int max_zichtbare_afstand = 55; //afstand in cm die we onderzoeken, verder zien we niet!
// wanneer stoppen?
int stop_afstand = 5; // stopt aan 10 cm
float distance_object;
bool invert_search_dir = false;

bool onsearchfield = false;
unsigned long prevtimewhitefield = 0UL;
bool finished = false;
#define NO_OBJECT      0
#define OBJECT_FAR     1
#define OBJECT_NEAR    2
#define OBJECT_COLLIDE 3


void setup(){
  if (newbat) {
    calib_max_speed = 180; //maximum value you want
    calib_no_speed  =  110; //lowest value that motors don't move anymore
    SLOW_SPEED      = 120;         //a slow speed good for searching
    turn_correction =  40;
    calib_speed_corrR = 0;  //if motors deviate, correct it
    calib_speed_corrL = 0; //if motors deviate, correct it
    corr_pushL = 0;
    corr_pushR = 0;
    search_turn_speed = 100;
    backward_speed = -calib_max_speed+turn_correction;
    backward_time = 500UL;
    if (ROBOT==THIEMEN)
      {calib_max_speed = 150;
      } else if (ROBOT==BLSTEF)
      {calib_max_speed = 140;
       calib_no_speed = 75;
      } else if (ROBOT==MLOUISE)
      {calib_max_speed = 130;
       calib_no_speed = 90;
       turn_correction =  40;
       backward_speed = -80;
      } else if (ROBOT==JASPER)
      {calib_max_speed = 130;
       search_turn_speed = 140;
       calib_no_speed = 80;
       backward_time = 300UL;
       corr_pushL=20;
      }else if (ROBOT==SAYA)
      {calib_max_speed = 140;
       calib_no_speed = 100;
       calib_speed_corrR = -10;
      };
  } else {
  //old batteries
    calib_max_speed = 240; //maximum value you want
    calib_no_speed  = 110; //lowest value that motors don't move anymore
    SLOW_SPEED      = 200;         //a slow speed good for searching
    turn_correction =   0;
    search_turn_speed = 220;
    backward_speed = -calib_max_speed+turn_correction;
  }
  if (ROBOT == THIEMEN){
    black[0] = 700;
  } else if (ROBOT == JASPER){
    black[0] = 700;
    white[1] = 400;
  }
  if (ROBOT == SAYA){
    corrwhite[0]=0;corrwhite[1]=0;corrwhite[2]=0;corrwhite[3]=20;corrwhite[4]=190;
    corrblack[0]=0;corrblack[1]=50;corrblack[2]=0;corrblack[3]=20;corrblack[4]=50;
  } else if (ROBOT == GUDRUN){
    corrwhite[0]=0;corrwhite[1]=0;corrwhite[2]=50;corrwhite[3]=0;corrwhite[4]=0;
    corrblack[0]=0;corrblack[1]=-10;corrblack[2]=20;corrblack[3]=0;corrblack[4]=0;
  } else if (ROBOT == THIEMEN){
    corrwhite[0]=0;corrwhite[1]=0;corrwhite[2]=0;corrwhite[3]=0;corrwhite[4]=0;
    corrblack[0]=0;corrblack[1]=70;corrblack[2]=50;corrblack[3]=30;corrblack[4]=40;
  } else if (ROBOT == JASPER){
    invert_search_dir = false;
    //corrwhite[0]=100;corrwhite[1]=0;corrwhite[2]=0;corrwhite[3]=0;corrwhite[4]=100;
    //corrblack[0]=0;corrblack[1]=0;corrblack[2]=0;corrblack[3]=0;corrblack[4]=0;
    corrwhite[0]=30;corrwhite[1]=0;corrwhite[2]=0;corrwhite[3]=0;corrwhite[4]=0;
    corrblack[0]=0;corrblack[1]=0;corrblack[2]=0;corrblack[3]=0;corrblack[4]=0;
  } else if (ROBOT == BLSTEF){
    corrwhite[0]=40;corrwhite[1]=0;corrwhite[2]=0;corrwhite[3]=0;corrwhite[4]=0;
    corrblack[0]=40;corrblack[1]=0;corrblack[2]=0;corrblack[3]=0;corrblack[4]=0;
  } else if (ROBOT == STEF){
    corrwhite[0]=0;corrwhite[1]=0;corrwhite[2]=100;corrwhite[3]=0;corrwhite[4]=0;
    corrblack[0]=0;corrblack[1]=0;corrblack[2]=0;corrblack[3]=0;corrblack[4]=0;
  } else if (ROBOT == MLOUISE){
    invert_search_dir = true;
    corrwhite[0]=0;corrwhite[1]=0;corrwhite[2]=0;corrwhite[3]=100;corrwhite[4]=40;
    corrblack[0]=0;corrblack[1]=0;corrblack[2]=0;corrblack[3]=0;corrblack[4]=0;
  }
  if (test) {
    Serial.begin(9600);
  }
  // aansluitingen sensor
  pinMode(trigPin, OUTPUT);
  pinMode(echoPin, INPUT);
  
  pinMode(motorlinksPWM, OUTPUT);
  pinMode(motorlinksDir, OUTPUT);
  pinMode(motorrechtsPWM, OUTPUT);
  pinMode(motorrechtsDir, OUTPUT);
}

void loop(){
  //unset slowdown if longer than 4 sec
  if (extra_slowdown > 0 && (millis()-slowdown_start > 4000UL)) {
    extra_slowdown = 0;
  }
  //Reads sensor values and computes sensor sum and weighted average
  int nrseen = 0;
  int lineseen = sensors_read();
  onsearchfield = false;
  switch (lineseen) {
    case LS_BLACKLINE:
    case LS_BLACKBANKLEFT:
    case LS_BLACKLEFT:
    case LS_BLACKBANKRIGHT:
    case LS_BLACKRIGHT:
      finished = false;
      onsearchfield = false;
      calc_turn();
      //Computes the error to be corrected
      motor_drive(right_speed, left_speed); //Sends PWM signals to the motors
      break;
    case LS_UNKNOWN:
      //can't decide what we have seen. stop and read again
      motor_drive(0, 0);
      if (test) {
        Serial.println("No line seen !!!");
      }
      break;
    case LS_WHITEFIELD:
      motor_drive(0,0);
      onsearchfield = false;
      if (test) {
        Serial.println("white line !!!");
      }
      if (millis() - prevtimewhitefield < 1500UL) {
        //really on white field
        motor_drive(0,0);
        onsearchfield = true;
      } else {
        //back up a bit to find the line again
        prevtimewhitefield = millis();
        motor_drive(0,0);
        delay(100);
        motor_drive(backward_speed, backward_speed);
        delay(backward_time);
        motor_drive(0,0);
        delay(100);
        // slow down before continuing
        extra_slowdown = (calib_max_speed - SLOW_SPEED)/2;
      }
//      //we do three repeats
//      for (int seeagain=0; seeagain<3; seeagain++) {
//        if (LS_WHITEFIELD == sensors_read()){
//          nrseen += 1;
//          delay(200);
//        }
//      }
//      if (nrseen == 3) {
//        onsearchfield = true;
//      } else {
//        onsearchfield = false;
//      }      
      if (!finished && onsearchfield){
        search_object();
        move_to_object();
        push_object();
      } // else: make him follow line again next loop
      break;
    case LS_BLACKFIELD:
      //a black field. here we should stop. wait a sec, try again, if still problem, go backward a bit, try again?
      motor_drive(0, 0);
      break;
    case LS_BLACKEXTREMELEFT:
      // we assume a sharp turn to left
      motor_drive(calib_max_speed-turn_correction, -calib_max_speed+turn_correction);
      delay(100);
      motor_drive(0,0);
      break;
//    case LS_BLACKBANKLEFT:
//      // we assume a sharp turn to left
//      motor_drive(calib_max_speed-turn_correction, 0);
//      delay(100);
//      motor_drive(0,0);
//      break;
    case LS_BLACKEXTREMERIGHT:
      // we assume a sharp turn to right
      motor_drive(-calib_max_speed+turn_correction , calib_max_speed-turn_correction);
      delay(100);
      motor_drive(0,0);
      break;
//    case LS_BLACKBANKRIGHT:
//      // we assume a sharp turn to right
//      motor_drive(0 , calib_max_speed-turn_correction);
//      delay(100);
//      motor_drive(0,0);
//      break;
    default:
      motor_drive(0, 0);
      break;
  }
  if (finished){
    motor_drive(0, 0);
  }
}

boolean sensors_read(){
  /*
  Method to read the sensors. Return type of black seen, and does
  necessary computations to know where the line is.
  */
  int sensors_sum = 0;
  int sensors_sum_bl = 0;
  int baseline = 1024;
  int topline = 0;
  sensors_average = 0;
  sensors_average_bl = 0;
  for (int i = 0; i < 5; i++){
    sensors[i] = analogRead(i);
    if (sensors[i] < 501){ sensors[i] = sensors[i]-corrwhite[i];}
    else { sensors[i] = sensors[i]-corrblack[i];}
    if (baseline > sensors[i]){
      baseline = sensors[i];
    }
    if (topline < sensors[i]){
      topline = sensors[i];
    }
  }
  for (int i = 0; i<5; i++){
    int val = sensors[i];
    sensors_average += val * i;
    //Calculating the weighted mean 
    sensors_sum += val;
    sensors_average_bl += (val-baseline) * i; 
    //Calculating the weighted mean maar nu trekken we laagste waarde ervan af
    sensors_sum_bl += val-baseline;
  }
  sensors_average=sensors_average/sensors_sum;         // gewogen gemiddelde
  sensors_average_bl=sensors_average_bl/sensors_sum_bl;// gewogen gemiddelde met baseline
  
  //de foutwaarde
  error_value = long((sensors_average_bl - mid_point) * SCHAAL_FOUT);

  int seen = LS_UNKNOWN;
  if (baseline > black[0]){
    seen = LS_BLACKFIELD;
  } else if (topline < white[1]){
    seen = LS_WHITEFIELD;
  } else if (topline-baseline < ACCURACY){
    // no line seen but not black or white field
    seen = LS_UNKNOWN;
  } else if (sensors[2] < white[1] && sensors[0] > black[0] && sensors[4] > black[0]) {
    seen = LS_BLACKSPLIT;
  } else if (sensors[0] < white[1] && sensors[3] > black[0] && sensors[2] < black[0]) {
    seen = LS_BLACKLEFT;
  } else if (sensors[0] < white[1] && sensors[3] > black[0] && sensors[4] > black[0]) {
    seen = LS_BLACKBANKLEFT;
  } else if (sensors[0] < white[1] && sensors[4] > black[0]) {
    seen = LS_BLACKEXTREMELEFT;
  } else if (sensors[4] < white[1] && sensors[1] > black[0] && sensors[2] < black[0]) {
    seen = LS_BLACKRIGHT;
  } else if (sensors[4] < white[1] && sensors[0] > black[0] && sensors[1] > black[0]) {
    seen = LS_BLACKBANKRIGHT;
  } else if (sensors[4] < white[1] && sensors[0] > black[0]) {
    seen = LS_BLACKEXTREMERIGHT;
  } else {
    seen = LS_BLACKLINE;
  }
  if (test) {
    motor_drive(0,0);
    Serial.print("prev speed: "); Serial.print(right_speed); Serial.print(" "); Serial.println(left_speed);
    Serial.print("I see:"); Serial.println(seen);
    Serial.print("Corrected measured: "); 
    for (int i = 0; i<5; i++){
      Serial.print(sensors[i]);Serial.print(" ");
    }
    Serial.println(" ");
    delay(2000);
  }
  return seen;
}

void search_object(){
  //we look for the object. First rotate left 180 degrees
  motor_drive(0,0);
      if (test) {
        Serial.println("Searching object!");
      }
  //delay(1000);
  //now rotate and scan
  if (invert_search_dir) {
    motor_drive(search_turn_speed,-search_turn_speed);
  } else {
    motor_drive(-search_turn_speed,search_turn_speed);
  }
  bool cont = true;
  while (cont) {
    switch (measure_distance(distance_object)) {
      case OBJECT_FAR:
      case OBJECT_NEAR:
      case OBJECT_COLLIDE:
        motor_drive(0,0);
        cont = false;
        break;
    }
  }
}

int measure_distance(float &distance){
  //determine how far an obstacle is
  // bepalen van afstand tot het blikje
  int duration;
  // 1 milliseconde kijken wat afstand van blik is
  digitalWrite(trigPin, HIGH);
  delayMicroseconds(1000);
  digitalWrite(trigPin, LOW);
  // berekenen afstand in cm (test dit en pas breuk aan als nodig!
  duration = pulseIn(echoPin, HIGH, timeout_echo);
  //Merk op: Out of range == 0 cm!
  distance = (duration/2) / 29.1;
  if (test) {
        Serial.print("Dist ");Serial.print(distance);Serial.println(" ");
    }
  if (distance <= 0 || distance >= max_zichtbare_afstand){
    distance = max_zichtbare_afstand;
    return NO_OBJECT;
  } else if (distance > max_zichtbare_afstand/2.) {
    return OBJECT_FAR;
  } else if (distance > stop_afstand) {
    return OBJECT_NEAR;
  } else {
    return OBJECT_COLLIDE;
  }
}

void move_to_object(){
  //we go to object as long as we are on WHITEFIELD
  int speedval;
      if (test) {
        Serial.println("Moving to object");
      }
  motor_drive(0,0);
  int pos_obj;
  //pos_obj = measure_distance(distance_object);
  bool cont=true;
  while (cont){
    pos_obj = measure_distance(distance_object);
    switch (pos_obj){
      case NO_OBJECT:
        //problem, research the object
        search_object();
        break;
      case OBJECT_FAR:
      case OBJECT_NEAR:
        speedval = min(calib_max_speed, calib_max_speed * max(SLOW_SPEED/(calib_max_speed*1.0), (distance_object)/(max_zichtbare_afstand)));
        Serial.print("Moving with speed ");Serial.println(speedval);
        motor_drive(speedval, speedval);
        delay(500);
        //motor_drive(0, 0);
        break;
      case OBJECT_COLLIDE:
        motor_drive(SLOW_SPEED, SLOW_SPEED);
        cont=true;
        break;
    }
    // test if still WHITEFIELD !
    int nrwhite = 0;
    int lineseen;
    for (int ind=0; ind<5; ind++) {
      lineseen = sensors_read();
      if (lineseen == LS_WHITEFIELD) {nrwhite++;}
    }
    if (nrwhite < 4) {
      //problem, at edge of field!, stop and search next cycle.
      cont = false;
      motor_drive(-180,180);
      delay(500);
      motor_drive(0,0);
    }
  }
}

void push_object(){
  // we now are or in front of object, or on edge search field. In first case, push it out.
      if (test) {
        Serial.println("Pushing object");
      }
  int pos_obj = measure_distance(distance_object);
  if (pos_obj == OBJECT_COLLIDE) {
    //we drive forward slowly for 7 sec?
    motor_drive(calib_max_speed+corr_pushL, calib_max_speed+corr_pushR);
    delay(8000);
    motor_drive(calib_max_speed,-calib_max_speed);
    delay(2000);
    //finished = true;
    motor_drive(0,0);
  }
}

void calc_turn(){
  
  //Restricting the error value between -max_err, -min_err and min_err, max_err.
  if (error_value > max_err){
    // not possible ...
    error_value = max_err;
  } else if (error_value < -max_err) {
    // not possible ...
    error_value = -max_err;
  }
  if (abs(error_value) < min_err){
    // don't correct yet
    error_value = 0;
  }
  //convert to correct number
  speed_corr = float(error_value)/float(max_err) * (calib_max_speed-calib_no_speed);
  if (error_value < -1000) {
    //line at sensor 0 move line slowly towards 2 (to left), by a right turn, so reducing speed right
    right_speed = 0; 
    left_speed = SLOW_SPEED;
    if (ROBOT == THIEMEN) {
      right_speed = -SLOW_SPEED;
      left_speed  = SLOW_SPEED;
    }
  } else if (error_value < 0){
    //line at sensor 0 to 2, move line towards 2 (to left), by reducing speed right
    right_speed = calib_max_speed + speed_corr;
    left_speed = calib_max_speed;
    if (ROBOT == THIEMEN) {
      left_speed  = calib_max_speed + 2*speed_corr;
    }
  } else if (error_value > 1000) {
    //line at sensor 4 move line slowly towards 3 (to right), by a left turn, so reducing speed left
    right_speed = SLOW_SPEED;
    left_speed = 0;
    if (ROBOT == THIEMEN) {
      right_speed = SLOW_SPEED;
      left_speed  = -SLOW_SPEED;
    }
  } else {
    //line at sensor 2 to 4, move line towards 2, by reducing speed left
    right_speed = calib_max_speed;
    left_speed = calib_max_speed - speed_corr;
    if (ROBOT == THIEMEN) {
      left_speed  = calib_max_speed - 2*speed_corr;
    }
  }
}

void motor_drive(int right_speed, int left_speed){
  // Drive motors according to the given values
  int sgvr = 1;
  if (right_speed != 0) {sgvr = abs(right_speed)/right_speed;}
  int sgvl = 1;
  if (left_speed != 0) {sgvl = abs(left_speed)/left_speed;}
  int vr = abs(right_speed) - extra_slowdown + calib_speed_corrR;
  int vl = abs(left_speed) - extra_slowdown + calib_speed_corrL;
  if (vr > calib_max_speed) {vr = calib_max_speed;}
  else if (vr<0) {vr = 0;}
  vr = vr * sgvr;
  if (vl > calib_max_speed) {vl = calib_max_speed;}
  else if (vl<0) {vl = 0;}
  vl = vl * sgvl;
  
  if (right_speed>=0){
    digitalWrite(motorrechtsDir, LOW); //vooruit
    analogWrite(motorrechtsPWM, vr);
  } else {
    digitalWrite(motorrechtsDir, HIGH); //achteruit
    analogWrite(motorrechtsPWM, 255+vr);
  }
  if (left_speed>=0){
    digitalWrite(motorlinksDir, LOW); //vooruit
    analogWrite(motorlinksPWM, vl);
  } else {
    digitalWrite(motorlinksDir, HIGH); //achteruit
    analogWrite(motorlinksPWM, 255+vl);
  }
}

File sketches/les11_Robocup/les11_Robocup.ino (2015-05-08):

/*******************************************/
/* Robocup Junior basis code
/*  Volg een parcours
/*  Na bepaalde tijd: zoek geel veld, en zoek object om te redden
/*  
/*******************************************/

#include <Servo.h>
#include "DistSens.h"

/********************************************/
/* Gegevens rond de bouw van je auto. 
/********************************************/
// pinnen voor de servo motor
#define servoLpin 9
#define servoRpin 10
// correctiewaarde indien bij rechtdoor auto niet rechtdoor rijd
// Voor de wedstrijd: laat de auto licht naar links afwijken gezien parcours
// voornamlijk naar rechts draaien is.
int correctieL = 0;
int correctieR = 0;

// alles rond afstand:
#define trigPin 12
#define echoPin 13
//maximum afstand in cm die we willen zien (bv bij redden)
#define MAX_AFSTAND 50.
//minimum afstand die sensor kan zien in cm (afhankelijk van waar je sensor staat)
#define MIN_AFSTAND 3.5

//voor lijnvolgred, vanaf wanneer redden mogelijk maken in ms
unsigned long time_red_na = 30000UL;
unsigned long time_vertraag_vanaf = 20000UL;

// alles rond lijnsensor
#define ANALOGSENS false
#define POLULU false
#define lijnLpin  2  // digital pin normaal, analog A2 als ANALOGSENS==true
#define lijnRpin  3  // digital pin normaal, analog A3 als ANALOGSENS==true

//snelheden van 0 (stilstaan) tot 100 (vol vooruit)
int lijn_snelheid = 15;  //niet te vlug of je schiet over de zwarte lijn!
#define lijn_snelheid_traag 10 //vanaf traag
#define lijn_draaihard 20  //als zwart onder sensor, draaihard om te corrigeren

/********************************************/
/* Code
/********************************************/
Servo servo1;
Servo servo2;
DistSens distsens;

// positie servo's. Start: stilstaan 
// waarde in percenten -100 .. 100
int servL = 0;
int servR = 0;

// bijhouden tijd
unsigned long timesec,   timesecbegin  =0UL;
unsigned long timemilli, timemillibegin=0UL;
unsigned long timemicro, timemicrobegin=0UL;

//variabelen om mee te rekenen
float afstand=0;

// alles rond lijnsensor
#define nrlijnpin 2
int lijnpins[]  = {lijnLpin, lijnRpin};
#define ZWART 0
#define WIT   1
int lijnsens[] = {ZWART, ZWART};  // waarde per sensor
int statuslijn;
// Wat kunnen we zien met de 2 lijnsensoren
#define LS_LIJNMIDDEN 0
#define LS_LIJNLINKS  1
#define LS_LIJNRECHTS 2
#define LS_ZWARTVELD  3

//algemene zaken autorobot
#define ROBOT_LIJNVOLG    0
#define ROBOT_REDDER      1
#define ROBOT_ONTWIJK     2
#define ROBOT_IR          3
#define ROBOT_LIJNVOLGRED 4
//robocup is lijnvolgen en redden:
int statusrobot = ROBOT_LIJNVOLGRED; 

#define LS_WAGGEL  0
#define LS_TRAAG   1
#define LS_SNEL    2
//lijn volgen door traag te gaan
//wijzig de strategie van lijn volgen naar wens!
int lijnstrategie = LS_TRAAG;

//bijhouden wanneer laatst zwarte lijn gezien
unsigned long time_blackline = timemillibegin;

//andere variabelen
int munt=0;
bool test=false;

void setup() {  
  distsens.attach(trigPin, echoPin);
  distsens.setMinMax(MIN_AFSTAND, MAX_AFSTAND);
  servo1.attach(servoLpin);
  servo2.attach(servoRpin);
  set_servos(servL, servR); //startsnelheid
  //pins lijnsensor hebben geen setup nodig!
  dotime();                 //tijd bijhouden
  randomSeed(analogRead(0));
  
  //geen afstand meten bij start
  distsens.stop();
}

void loop() {
  dotime();
  if (timemilli > time_vertraag_vanaf) lijn_snelheid = lijn_snelheid_traag;
  
  if (statusrobot == ROBOT_LIJNVOLGRED) {
    //lijn op grond lezen
    leeslijn();
    if (lijnstrategie == LS_TRAAG) {
      traaglijnvolgen();
    } else {
      //nog schrijven!!
      stopauto();
    }
    if (timemilli > time_red_na) {
      // controleer dat we lijn zien elke 1.5 sec
      if (timemilli - time_blackline > 1500UL) {
        //zoek de zwarte lijn
        bool zwart_gevonden = zoek_zwart();
        if (zwart_gevonden==false) {
          //zwart niet gevonden, schakel over op redden!
          statusrobot = ROBOT_REDDER;
          //start afstandmeting
          distsens.start();
          stopauto();
        }
      }
    }
  }
  
  if (statusrobot == ROBOT_REDDER) {
    // gebruik hier een van de afstandsmeting methoden
    //afstand = distsens.distSimple();
    //afstand = distsens.distTimeout();
    afstand = distsens.distNoblock();
    if (afstand == 0) {
      //niets te zien, draai traag rond
      //we doen dit door elke 100ms van een seconde te draaien, anders niet
      // timemilli % 500 heeft de rest terug bij deling door 500!
      if (timemilli % 350 < 50) {
        rechtshard(100);
      } else {
        stopauto();
      }
    } else {
      //traag vooruit
      if (afstand > 12) {
        //niet te vlug ernaartoe
        vooruit(60);
      } else {
        //dichtbij, duw het!
        vooruit(100);
        //doe dit 6 seconden lang
        delay(6000);
      }
    }
  }
}

void traaglijnvolgen(){
    if (statuslijn == LS_LIJNMIDDEN) {
      vooruit(lijn_snelheid);
    } else if (statuslijn == LS_LIJNLINKS) {
      linkshard(lijn_draaihard);
      //niet overshooten
    } else if (statuslijn == LS_LIJNRECHTS) {
      rechtshard(lijn_draaihard);
      //niet overshooten
    } else if (statuslijn == LS_ZWARTVELD) {
      //oeps. probeer te herstellen 
      rechtshard(lijn_draaihard);
      //niet overshooten
    }
}

void snellijnvolgen(){
  //werkt NIET!! Aanpassen naar eigen idee
    if (statuslijn == LS_LIJNMIDDEN) {
      vooruit();
    } else if (statuslijn == LS_LIJNLINKS) {
      //niet overshooten
      achteruit(10);
      delay(500);
      //nu actie
      links();
    } else if (statuslijn == LS_LIJNRECHTS) {
      //niet overshooten
      achteruit(10);
      delay(500);
      //nu actie
      rechts();
    } else if (statuslijn == LS_ZWARTVELD) {
      //oeps. probeer te herstellen 
      //niet overshooten
      achteruit(10);
      delay(500);
      //nu actie
      rechtshard();
    }
}

void leeslijn()
{
  for (int i=0;i<nrlijnpin;i++){
    if (ANALOGSENS) {
      //lees analoog de lijn sensoren
      // Calibreer grenswaarde van 700 !
      int val = analogRead(lijnpins[i]);
      Serial.print(" Reading analog ... ");Serial.println(val);
      if ( val < 700) {
        //wit
        lijnsens[i] = 1;
      } else {
        //wit
        lijnsens[i] = 0;
      };
    } else {
      //digitaal zwart of niets
      if (POLULU) {
        lijnsens[i] = readQLDigital(lijnpins[i]);
      } else {
        lijnsens[i] = digitalRead(lijnpins[i]);
      }
    }
  }
  verwerklijn();
}

void verwerklijn()
{
  if      (lijnsens[0] == WIT   && lijnsens[nrlijnpin-1] == WIT) 
    statuslijn = LS_LIJNMIDDEN;
  else if (lijnsens[0] == ZWART && lijnsens[nrlijnpin-1] == WIT) {
    statuslijn = LS_LIJNLINKS;
    time_blackline = timemilli;    
  } else if (lijnsens[0] == WIT   && lijnsens[nrlijnpin-1] == ZWART) {
    statuslijn = LS_LIJNRECHTS;
    time_blackline = timemilli; 
  } else {
    //beide lezen zwart.
    statuslijn = LS_ZWARTVELD;
    time_blackline = timemilli; 
  }
}
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

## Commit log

2014-01-25 Add different sketches for calibrations of part of the motor: * moving forward and left right * detecting colors and lines * following a line
2014-01-25 allow follow up of error control via PID
    [calib_light_sensor_setpoint_line_follow.ino]
2014-02-10 bug in motor code
    [linefollow_les3_extend.ino]
2014-02-11 add calibration for distance sensor
2014-02-11 correct motor movement
2014-02-13 first frames, correction in doc
    [calib_forward_line_follow_extend.ino]
2014-02-13 update the frame for a roof and tail for stability
2014-02-13 update of the frames
2014-02-13 converge in one frame file
2014-02-18 Changed svg for saya frame, circuit in fritzing
    [autorobot_complete.fzz]
2014-02-18 changes to the basic frame
2014-03-25 Improved calibration, working search push object calibration
2014-03-25 undo error introduced, tweak values
    [calib_forward_line_follow.ino, calib_forward_line_follow_extend.ino, calib_search_push_object.ino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]
2014-03-30 add in calibration of the different robots made
2014-05-10 * Make all robot specifics automatic based on ROBOT value * Add a slowdown after a problem in hope of recovering * Merge in search_turn_speed of robotdog * fix bug where prevtimewhitefield is reset a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
    [linefollow_search_push.ino, robothond.ino]
2014-05-17 bug: extra slowdown was too large
    [linefollow_search_push.ino]
2015-02-13 Library to work with arduino + distance sensors
2015-02-13 Aanpassen van appendix met de lessen
2015-02-14 Better avoiding: rotate somewhat longer so wheels don't get stuck even though eyes see nothing.
    [les04_ontwijkobjecten.ino]
2015-02-22 Add new frame basis
2015-04-18 Test the IR sensor
